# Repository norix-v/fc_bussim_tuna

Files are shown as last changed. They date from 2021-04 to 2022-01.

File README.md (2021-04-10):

# FC Cartridge bus simulator "tuna"

## What's it this?

This is famicom cartridge bus simulator 'kazzo' compatible hardware and extra software.  
The original project is [here](https://ja.osdn.net/projects/unagi/).  

## How to use

This data is provided "as is" and is freely available as long as you comply with the license.  
The author does not give an explanation or answer.  

## 何これ？

このプロジェクトはfamicom bus simulator 'kazzo' の互換のハードウェアとおまけのソフトウェアです。  
オリジナルのプロジェクトは[こちら](https://ja.osdn.net/projects/unagi/)です。  

## 使い方

このデータは"現状のまま"で提供され、ライセンスを遵守する限りにおいて自由に使用出来ます。なお、作者は説明も回答も致しませんのであしからず。

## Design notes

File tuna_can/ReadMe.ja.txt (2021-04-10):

tuna_can (ツナ缶）

--------
何これ？
--------

tuna（kazzoでも可）用のFCカートリッジの簡易デバッガです。
適当なアドレスにデータを書いたり読んだりダンプしてみたりするツールです。
スクリプトを作る際のお供にどうぞ。

起動時にヘルプが表示されているので使い方はわかると思います。
おまけでカーソルキー上下にヒストリ機能を搭載しています（最大64エントリ）。

----------
ビルド方法
----------

Visual Studio Community 2019でコンパイル出来ます。

----------
ライセンス
----------

LICENSE.ja.txtを参照してください。

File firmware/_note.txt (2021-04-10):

雑な解説

バスシミュレータを謳っていますが、実機と完全に同じではありません。

・PHI2のサイクルタイムは1.48MHz程度
　同じアクセスが続くだけでいいなら実機とほぼ同じまで出来るが…

・PHI2のエッジ対する/ROMSELの遅延は16nsです
　オシロスコープでそれくらいになっているのは確認

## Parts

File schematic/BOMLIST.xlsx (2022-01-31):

FC Cartridge bus simulator “tuna” BOM list
Reference | Qty | Value | Name | Package type | Note
C1 | 1 | 10uF | 10uF | 0805/2012 | Any manufacturer. Rated voltage should be 6.3V or higher.
C2,C3,C4,C5,C6,C7 | 6 | 0.1uF | 0.1uF | 0603/1608 | Any manufacturer. Rated voltage should be 6.3V or higher.
CN1 | 1 | FAMICOM_EDGE_CONNECTOR | 5530843-7 (TE Connectivity) CR22A-60D-2.54DS(70) (HIROSE) | Through hole | Card edge connector 2.54mm(0.1inch) pitch 60pins.
D1 | 1 | BAT43XV2 | BAT43VX2 (ON semiconductor) | SOD-523 | Any manufacturer with similar specifications.
D2 | 1 | ACCESS | OSO50805C1C (OptoSupply, Orange) | 0805/2012 | Any color, any manufacturer.
D3 | 1 | USB POWER | OSR50805C1C (OptoSupply, Red) | 0805/2012 | Any color, any manufacturer.
F1 | 1 | Polyfuse_Small | MF-PSMF020X-2 (Bourns) | 0805/2012 | Hold 200mA, Trip at 500mA. Any similar specifications.
Q1 | 1 | IRLML6402 | Pch MOSFET IRLML6402 | SOT-23 | Any manufacturer with similar specifications.
R1 | 1 | 10K | 10K ohm | 0603/1608 | Any manufacturer.
R2 | 1 | 150 | 150 ohm | 0603/1608 | Any manufacturer.
R3,R5 | 2 | 1K | 1K ohm | 0603/1608 | Any manufacturer.
R4 | 1 | 330 | 330 ohm | 0603/1608 | Any manufacturer.
RN1,RN2,RN3,RN4 | 4 | 4.7K | CAY16A-472J4LF (Bourns) | 4x0603 | Any manufacturer.
SW1 | 1 | SW_NKK_GW12LJPF | GW12LJPF (NKK Switches) | Through hole | Any like color.
U1 | 1 | Pico | Rasiberry Pi Pico RP2040 | SMD | The Raspberry Pi Foundation product.
U2 | 1 | SN74AHCT1G125DBV | Buffer | SOT-23-5 | Any manufacturer with similar specifications. TTL level input and input power down protection required.
U3,U4 | 2 | SN74CB3T3245PW | 8-channel FET bus switch with level shifter | TSSOP-20_4.4x6.5mm_P0.65mm | Texas Instruments Inc. only.
U5,U6 | 2 | 74VHCT574 | Octal flip flop | TSSOP-20_4.4x6.5mm_P0.65mm | Any manufacturer with similar specifications. TTL level input and input power down protection required.
Note: This BOM lists the ones used by the author. Compatible products exist for most parts.

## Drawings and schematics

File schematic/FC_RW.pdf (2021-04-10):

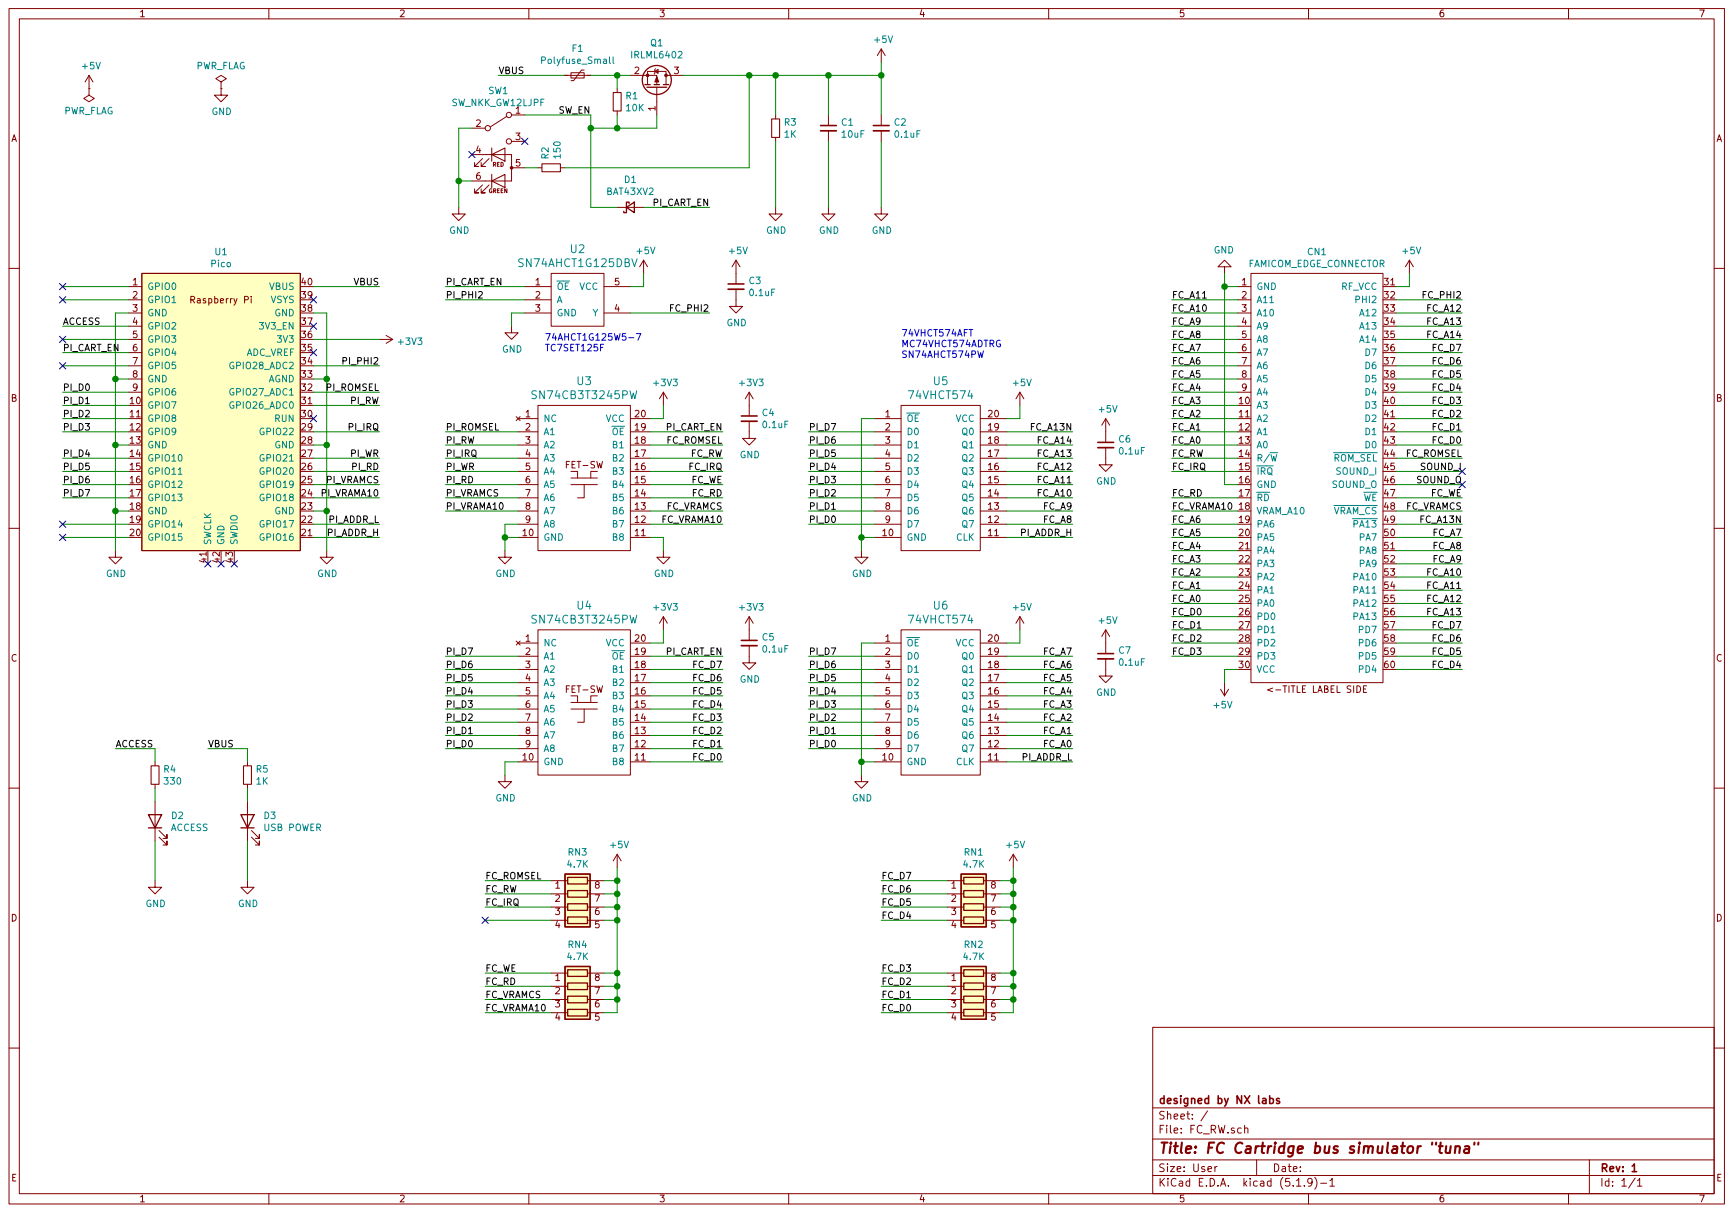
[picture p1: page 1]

74VHCT574
File: FC_RW.sch Sheet: / designed by NX labs C7

Id: 1/1 Title: FC Cartridge bus simulator "tuna"

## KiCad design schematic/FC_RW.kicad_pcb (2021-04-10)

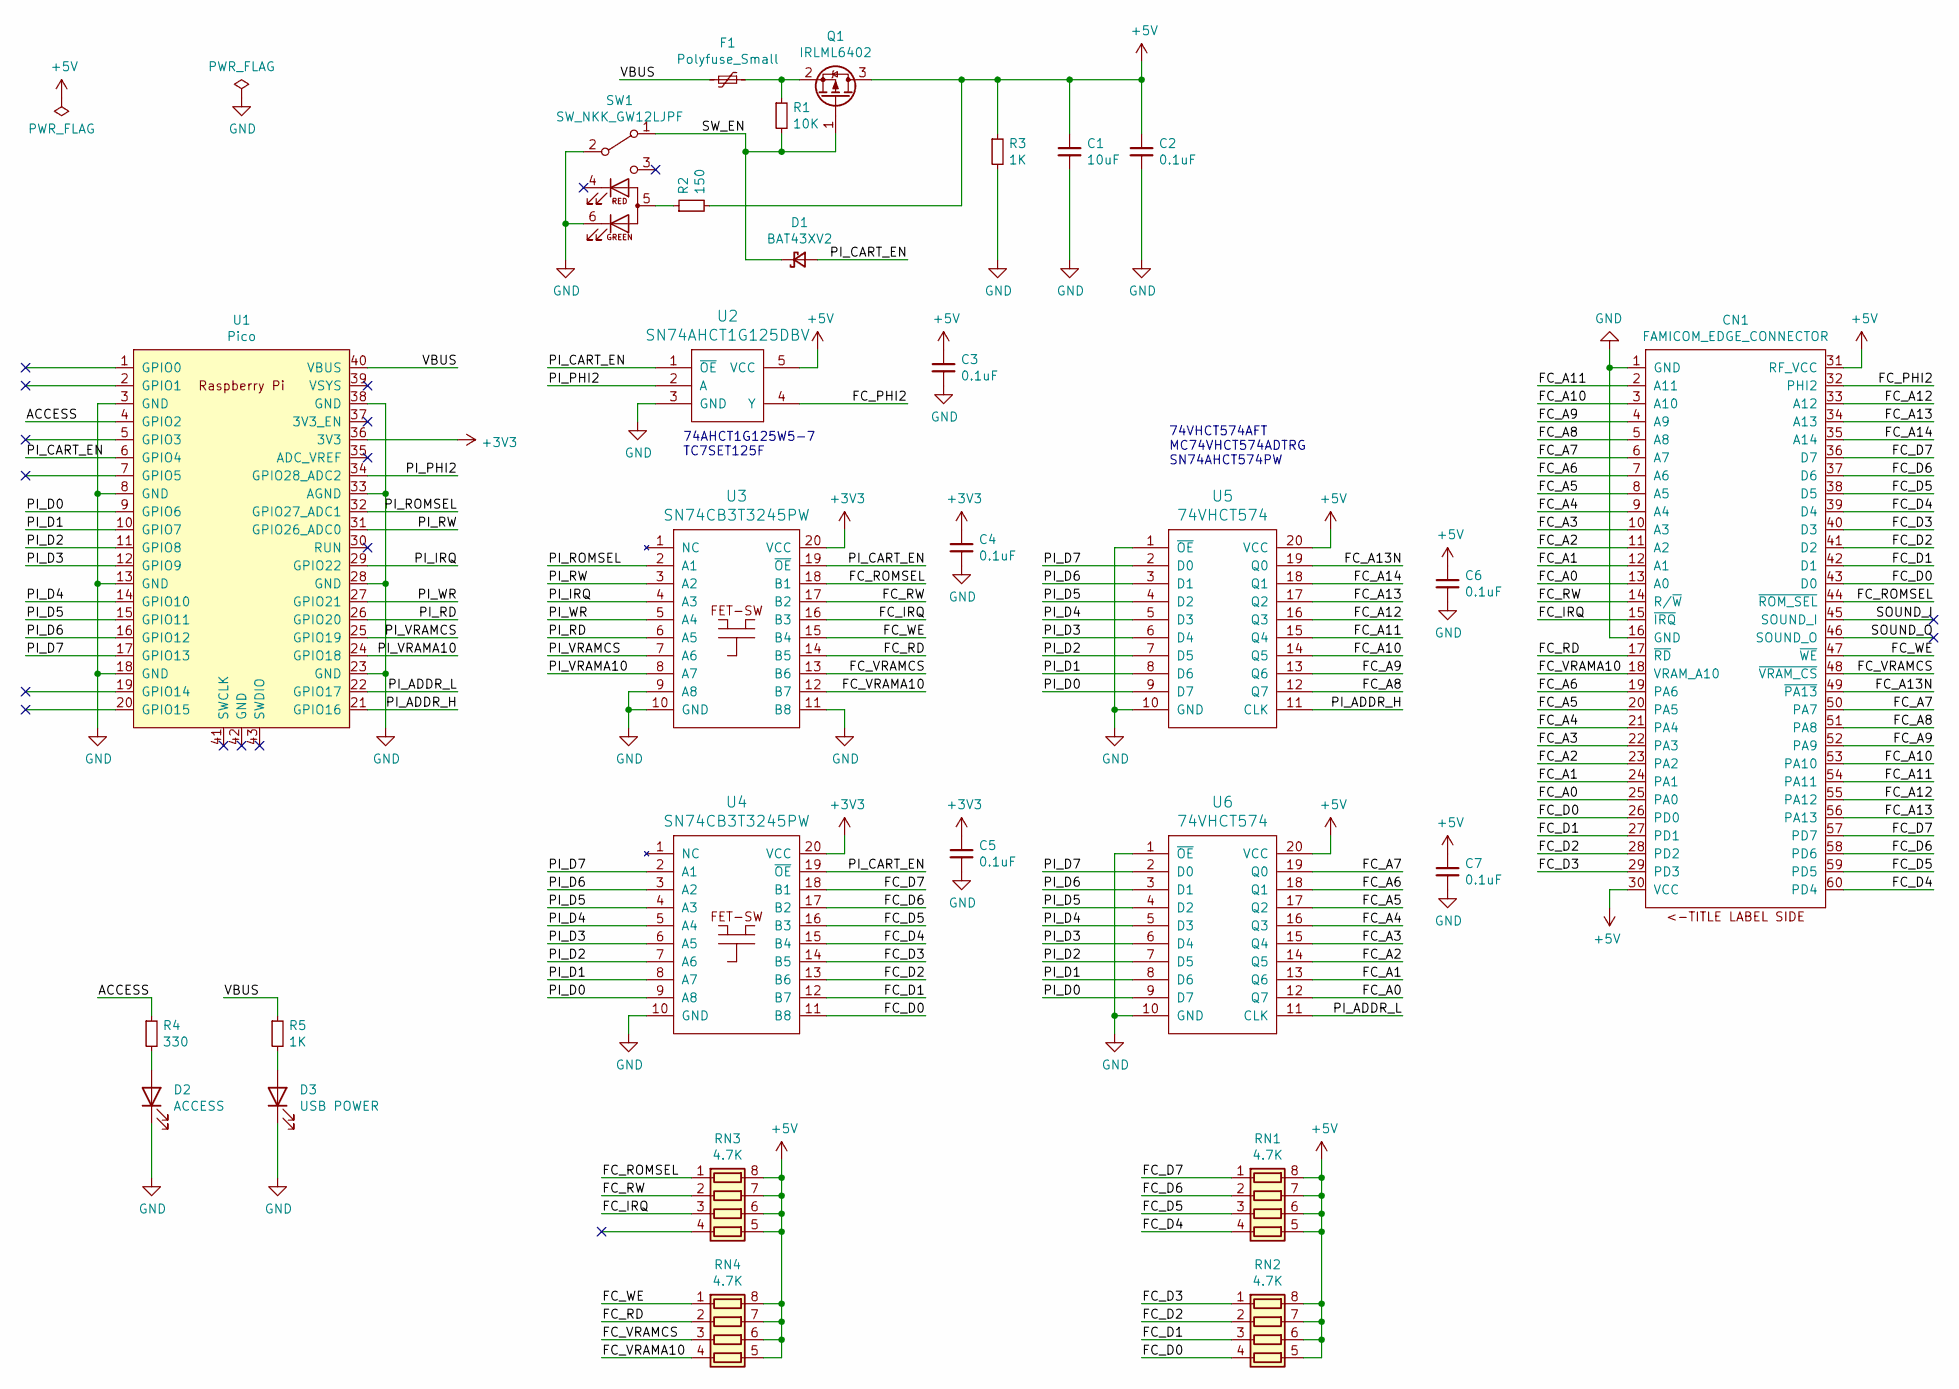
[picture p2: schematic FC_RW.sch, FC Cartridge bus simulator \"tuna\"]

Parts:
C1: 10uF; C_0805_2012Metric
C2, C3, C4, C5, C6, C7: 0.1uF; C_0603_1608Metric
CN1: FAMICOM_EDGE_CONNECTOR; Famicom_60pin
D1: BAT43XV2; D_SOD-523
D2: ACCESS; D_0805_2012Metric
D3: USB POWER; D_0805_2012Metric
F1: Polyfuse_Small; Fuse_0805_2012Metric
Q1: IRLML6402; SOT-23
R1: 10K; R_0603_1608Metric
R2: 150; R_0603_1608Metric
R3, R5: 1K; R_0603_1608Metric
R4: 330; R_0603_1608Metric
RN1, RN2, RN3, RN4: 4.7K; R_Array_Convex_4x0603
SW1: SW_NKK_GW12LJPF; SW_NKK_GW12LJP
U1: Pico; RPi_Pico_SMD_TH
U2: SN74AHCT1G125DBV; SOT-23-5
U3, U4: SN74CB3T3245PW; TSSOP-20_4.4x6.5mm_P0.65mm
U5, U6: 74VHCT574; TSSOP-20_4.4x6.5mm_P0.65mm

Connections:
+3V3: C4.1, C5.1, U1.36 (3V3), U3.20 (VCC), U4.20 (VCC)
+5V: C1.1, C2.1, C3.1, C6.1, C7.1, CN1.30 (VCC), CN1.31 (RF_VCC), Q1.3 (D), R2.2, R3.1, RN1.5 (R4.2), RN1.6 (R3.2), RN1.7 (R2.2), RN1.8 (R1.2), RN2.5 (R4.2), RN2.6 (R3.2), RN2.7 (R2.2), RN2.8 (R1.2), RN3.5 (R4.2), RN3.6 (R3.2), RN3.7 (R2.2), RN3.8 (R1.2), RN4.5 (R4.2), RN4.6 (R3.2), RN4.7 (R2.2), RN4.8 (R1.2), U2.5 (VCC), U5.20 (VCC), U6.20 (VCC)
/ACCESS: R4.1, U1.4 (GPIO2)
/FC_A0: CN1.13 (A0), CN1.25 (PA0), U6.12 (Q7)
/FC_A1: CN1.12 (A1), CN1.24 (PA1), U6.13 (Q6)
/FC_A2: CN1.11 (A2), CN1.23 (PA2), U6.14 (Q5)
/FC_A3: CN1.10 (A3), CN1.22 (PA3), U6.15 (Q4)
/FC_A4: CN1.9 (A4), CN1.21 (PA4), U6.16 (Q3)
/FC_A5: CN1.8 (A5), CN1.20 (PA5), U6.17 (Q2)
/FC_A6: CN1.7 (A6), CN1.19 (PA6), U6.18 (Q1)
/FC_A7: CN1.6 (A7), CN1.50 (PA7), U6.19 (Q0)
/FC_A8: CN1.5 (A8), CN1.51 (PA8), U5.12 (Q7)
/FC_A9: CN1.4 (A9), CN1.52 (PA9), U5.13 (Q6)
/FC_A10: CN1.3 (A10), CN1.53 (PA10), U5.14 (Q5)
/FC_A11: CN1.2 (A11), CN1.54 (PA11), U5.15 (Q4)
/FC_A12: CN1.33 (A12), CN1.55 (PA12), U5.16 (Q3)
/FC_A13: CN1.34 (A13), CN1.56 (PA13), U5.17 (Q2)
/FC_A13N: CN1.49 (~PA13), U5.19 (Q0)
/FC_A14: CN1.35 (A14), U5.18 (Q1)
/FC_D0: CN1.26 (PD0), CN1.43 (D0), RN2.4 (R4.1), U4.11 (B8)
/FC_D1: CN1.27 (PD1), CN1.42 (D1), RN2.3 (R3.1), U4.12 (B7)
/FC_D2: CN1.28 (PD2), CN1.41 (D2), RN2.2 (R2.1), U4.13 (B6)
/FC_D3: CN1.29 (PD3), CN1.40 (D3), RN2.1 (R1.1), U4.14 (B5)
/FC_D4: CN1.39 (D4), CN1.60 (PD4), RN1.4 (R4.1), U4.15 (B4)
/FC_D5: CN1.38 (D5), CN1.59 (PD5), RN1.3 (R3.1), U4.16 (B3)
/FC_D6: CN1.37 (D6), CN1.58 (PD6), RN1.2 (R2.1), U4.17 (B2)
/FC_D7: CN1.36 (D7), CN1.57 (PD7), RN1.1 (R1.1), U4.18 (B1)
/FC_IRQ: CN1.15 (~IRQ), RN3.3 (R3.1), U3.16 (B3)
/FC_PHI2: CN1.32 (PHI2), U2.4 (Y)
/FC_RD: CN1.17 (~RD), RN4.2 (R2.1), U3.14 (B5)
/FC_ROMSEL: CN1.44 (~ROM_SEL), RN3.1 (R1.1), U3.18 (B1)
/FC_RW: CN1.14 (R/~W), RN3.2 (R2.1), U3.17 (B2)
/FC_VRAMA10: CN1.18 (VRAM_A10), RN4.4 (R4.1), U3.12 (B7)
/FC_VRAMCS: CN1.48 (~VRAM_CS), RN4.3 (R3.1), U3.13 (B6)
/FC_WE: CN1.47 (~WE), RN4.1 (R1.1), U3.15 (B4)
/PI_ADDR_H: U1.21 (GPIO16), U5.11 (CLK)
/PI_ADDR_L: U1.22 (GPIO17), U6.11 (CLK)
/PI_CART_EN: D1.2 (A), U1.6 (GPIO4), U2.1 (~OE), U3.19 (~OE), U4.19 (~OE)
/PI_D0: U1.9 (GPIO6), U4.9 (A8), U5.9 (D7), U6.9 (D7)
/PI_D1: U1.10 (GPIO7), U4.8 (A7), U5.8 (D6), U6.8 (D6)
/PI_D2: U1.11 (GPIO8), U4.7 (A6), U5.7 (D5), U6.7 (D5)
/PI_D3: U1.12 (GPIO9), U4.6 (A5), U5.6 (D4), U6.6 (D4)
/PI_D4: U1.14 (GPIO10), U4.5 (A4), U5.5 (D3), U6.5 (D3)
/PI_D5: U1.15 (GPIO11), U4.4 (A3), U5.4 (D2), U6.4 (D2)
/PI_D6: U1.16 (GPIO12), U4.3 (A2), U5.3 (D1), U6.3 (D1)
/PI_D7: U1.17 (GPIO13), U4.2 (A1), U5.2 (D0), U6.2 (D0)
/PI_IRQ: U1.29 (GPIO22), U3.4 (A3)
/PI_PHI2: U1.34 (GPIO28_ADC2), U2.2 (A)
/PI_RD: U1.26 (GPIO20), U3.6 (A5)
/PI_ROMSEL: U1.32 (GPIO27_ADC1), U3.2 (A1)
/PI_RW: U1.31 (GPIO26_ADC0), U3.3 (A2)
/PI_VRAMA10: U1.24 (GPIO18), U3.8 (A7)
/PI_VRAMCS: U1.25 (GPIO19), U3.7 (A6)
/PI_WR: U1.27 (GPIO21), U3.5 (A4)
/SOUND_I: CN1.45 (SOUND_I)
/SOUND_O: CN1.46 (SOUND_O)
/SW_EN: D1.1 (K), Q1.1 (G), R1.2, SW1.1 (A)
/VBUS: F1.2, R5.1, U1.40 (VBUS)
GND: C1.2, C2.2, C3.2, C4.2, C5.2, C6.2, C7.2, CN1.1 (GND), CN1.16 (GND), D2.1 (K), D3.1 (K), R3.2, SW1.2 (B), SW1.6 (KG), U1.3 (GND), U1.8 (GND), U1.13 (GND), U1.18 (GND), U1.23 (GND), U1.28 (GND), U1.33 (AGND), U1.38 (GND), U2.3 (GND), U3.9 (A8), U3.10 (GND), U3.11 (B8), U4.10 (GND), U5.1 (~OE), U5.10 (GND), U6.1 (~OE), U6.10 (GND)
unnamed: D2.2 (A), R4.2
unnamed: D3.2 (A), R5.2
unnamed: F1.1, Q1.2 (S), R1.1
unnamed: R2.1, SW1.5 (A)

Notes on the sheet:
74VHCT574AFT MC74VHCT574ADTRG SN74AHCT574PW
74AHCT1G125W5-7 TC7SET125F

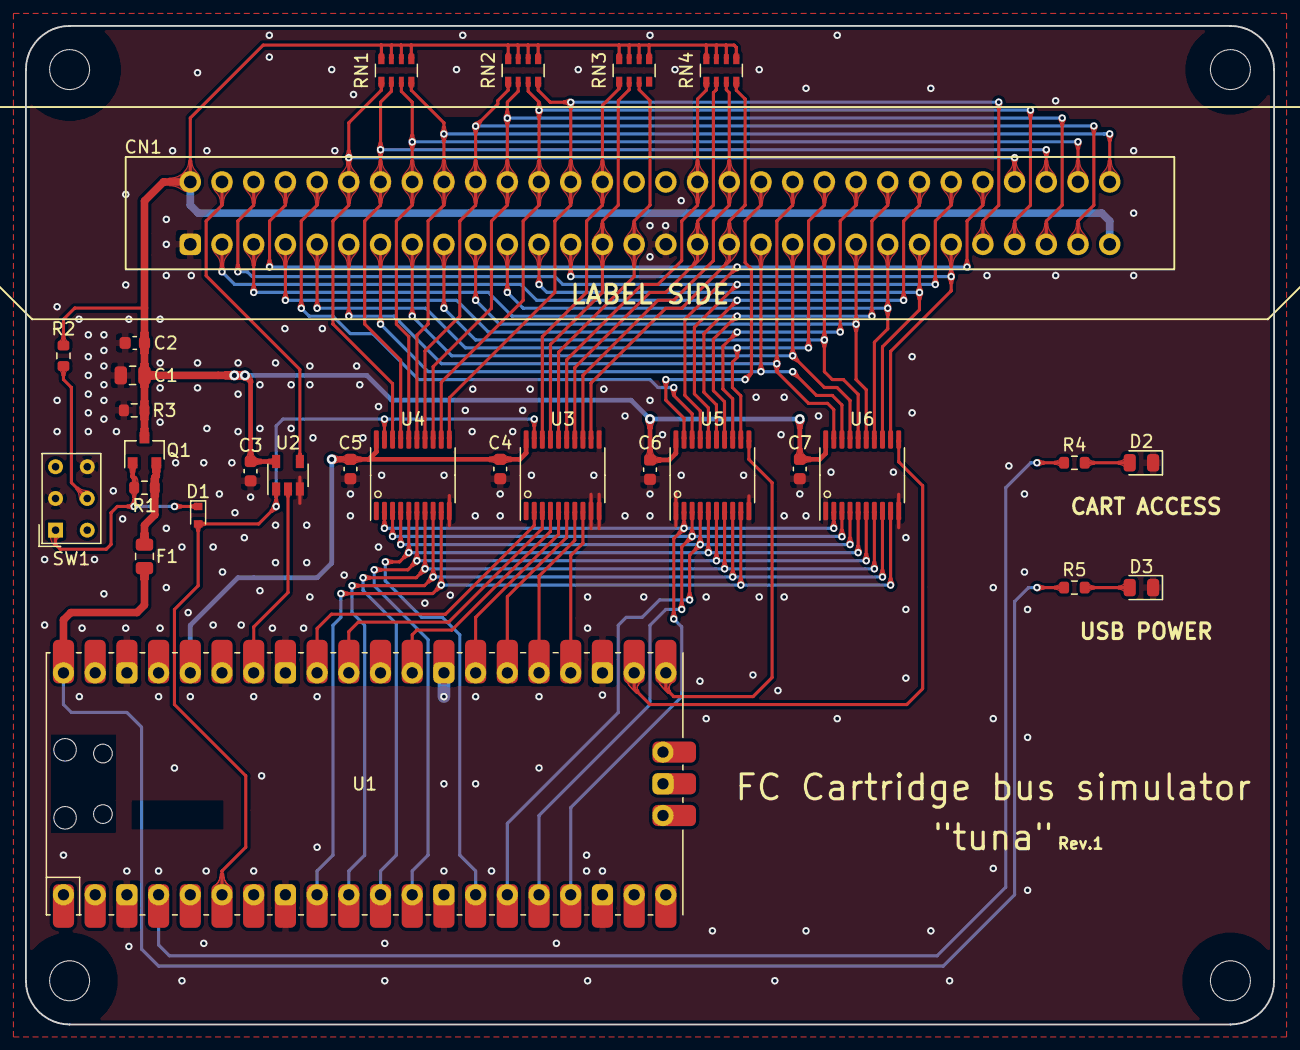
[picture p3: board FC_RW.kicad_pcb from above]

Board: 2 copper layers, 100.0 x 80.0 mm, 29 parts (0 on the bottom side), 61 nets.

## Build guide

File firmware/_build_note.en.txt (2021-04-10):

============
How to build
============

Explanation of how to set up the build environment will be omitted.

See
https://datasheets.raspberrypi.org/pico/getting-started-with-pico.pdf
for more information.

Since pico-sdk is included as a git submodule, it is not necessary to set PICO_SDK_PATH. may be.

Good luck!

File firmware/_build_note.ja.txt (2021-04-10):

==========
ビルド方法
==========

ビルド環境の設定方法の説明は省略します。

詳細については
https://datasheets.raspberrypi.org/pico/getting-started-with-pico.pdf
を参照してください。

pico-sdkはgitサブモジュールとして含まれているため、PICO_SDK_PATHを設定する必要はありません。たぶん。

Good luck!

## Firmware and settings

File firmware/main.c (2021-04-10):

//
// FC Cartridge bus simulator "tuna"
//
// Copyrighte (C) 2021 Norix (NX labs)
//
// License: GPL2 (see gpl-2.0.txt)
//
#include <stdio.h>
#include "pico/stdlib.h"
#include "pico/multicore.h"
#include "hardware/gpio.h"
#include "tusb.h"
#include "bsp/board.h"

#include "usb_drv.h"
#include "bus_sim.h"
#include "flash_memory.h"

int main()
{
	stdio_init_all();
	board_init();
	tusb_init();

	printf ("FC bus simulator \"tuna\"\n");

	multicore_launch_core1(bussim_process);
	uint32_t	data = multicore_fifo_pop_blocking();
	if (data != 0x2A032C02) {
		printf ("core1 launch failed..\n");
		while (1) {
			tight_loop_contents();
		}
	}

	printf ("launch core1 fifo:%08X\n", data);

	sleep_ms(5);
	while (1) {
		tud_task();
		kazzo_flash_process();
	}

    return 0;
}

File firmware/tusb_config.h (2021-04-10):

/*
 * The MIT License (MIT)
 *
 * Copyright (c) 2019 Ha Thach (tinyusb.org)
 *
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
 */

#ifndef _TUSB_CONFIG_H_
#define _TUSB_CONFIG_H_

#ifdef __cplusplus
 extern "C" {
#endif

//--------------------------------------------------------------------
// COMMON CONFIGURATION
//--------------------------------------------------------------------

// defined by board.mk
#ifndef CFG_TUSB_MCU
  #error CFG_TUSB_MCU must be defined
#endif

// RHPort number used for device can be defined by board.mk, default to port 0
#ifndef BOARD_DEVICE_RHPORT_NUM
  #define BOARD_DEVICE_RHPORT_NUM     0
#endif

// RHPort max operational speed can defined by board.mk
// Default to Highspeed for MCU with internal HighSpeed PHY (can be port specific), otherwise FullSpeed
#ifndef BOARD_DEVICE_RHPORT_SPEED
  #if (CFG_TUSB_MCU == OPT_MCU_LPC18XX || CFG_TUSB_MCU == OPT_MCU_LPC43XX || CFG_TUSB_MCU == OPT_MCU_MIMXRT10XX || \
       CFG_TUSB_MCU == OPT_MCU_NUC505  || CFG_TUSB_MCU == OPT_MCU_CXD56)
    #define BOARD_DEVICE_RHPORT_SPEED   OPT_MODE_HIGH_SPEED
  #else
    #define BOARD_DEVICE_RHPORT_SPEED   OPT_MODE_FULL_SPEED
  #endif
#endif

// Device mode with rhport and speed defined by board.mk
#if   BOARD_DEVICE_RHPORT_NUM == 0
  #define CFG_TUSB_RHPORT0_MODE     (OPT_MODE_DEVICE | BOARD_DEVICE_RHPORT_SPEED)
#elif BOARD_DEVICE_RHPORT_NUM == 1
  #define CFG_TUSB_RHPORT1_MODE     (OPT_MODE_DEVICE | BOARD_DEVICE_RHPORT_SPEED)
#else
  #error "Incorrect RHPort configuration"
#endif

// This example doesn't use an RTOS
//#define CFG_TUSB_OS               OPT_OS_NONE

// CFG_TUSB_DEBUG is defined by compiler in DEBUG build
//#define CFG_TUSB_DEBUG           0

/* USB DMA on some MCUs can only access a specific SRAM region with restriction on alignment.
 * Tinyusb use follows macros to declare transferring memory so that they can be put
 * into those specific section.
 * e.g
 * - CFG_TUSB_MEM SECTION : __attribute__ (( section(".usb_ram") ))
 * - CFG_TUSB_MEM_ALIGN   : __attribute__ ((aligned(4)))
 */
#ifndef CFG_TUSB_MEM_SECTION
#define CFG_TUSB_MEM_SECTION
#endif

#ifndef CFG_TUSB_MEM_ALIGN
#define CFG_TUSB_MEM_ALIGN          __attribute__ ((aligned(4)))
#endif

//--------------------------------------------------------------------
// DEVICE CONFIGURATION
//--------------------------------------------------------------------

#ifndef CFG_TUD_ENDPOINT0_SIZE
#define CFG_TUD_ENDPOINT0_SIZE    64
#endif

//------------- CLASS -------------//
#define CFG_TUD_CDC               0
#define CFG_TUD_MSC               0
#define CFG_TUD_HID               0
#define CFG_TUD_MIDI              0
#define CFG_TUD_VENDOR            1

// Vendor FIFO size of TX and RX
// If not configured vendor endpoints will not be buffered
#define CFG_TUD_VENDOR_RX_BUFSIZE	0x0100
#define CFG_TUD_VENDOR_TX_BUFSIZE	0x0100

#ifdef __cplusplus
 }
#endif

#endif /* _TUSB_CONFIG_H_ */

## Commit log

2021-04-16 Fixed cpu (ppu) _write_flash not to skip $FF.
    [bus_sim.c]
2022-01-31 fix BOM list
    [BOMLIST.xlsx]
